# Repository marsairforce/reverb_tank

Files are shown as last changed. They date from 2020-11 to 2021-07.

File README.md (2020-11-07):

# A stand alone spring reverb tank

Here I wanted to investigate using op-amps to drive the tank, rather than to build a tube circuit.

I already built a tube circuit into my Traynor amp, and I am very happy with how good it sounds.

I just had this spare reverb tank sitting on my shelf with nothing to make use of it. If i can build it into a "pedal" type of effect, I can power it from standard guitar pedal power supply and use it in my audio hobby work. Like as an effect for microphone for vocals. Or drums in reaper. Any time reverb is needed so I don't need to use an effect or impulse response, Since these always sound terrible to me.

But then I had the idea, Why not just build both as a stand-alone unit. Have a switch to change between which driver is used.

## Packaging

The reverb tank is quite long. If I could build a 1U rack case for this that might be fun. But then might as well build a power supply so this plugs in. I can create a stripped down version of the op-amp power supply, having a single fixed +/-15V regulated output. That power supply is super awesome. Smooth DC ouput

The challenge is I need to be able to create a metal chassis. or shell out to buy one.

I found one from Bud Industries for about half what the Hammond mfg one was. But the Hammond one is painted. This 1U chasis needs painting then. It is about $100 to get the chassis and lid.

But the idea is I think I can fit this into a 1U chassis.

## Op-Amp Driver

I am really inspired by the design from [Elliot Sound](https://sound-au.com/project34.htm) site.

I find it curious, that when doing a google search I found several foreign websites that look like a pintrest kind of site but caching super old versions of this page, the wording is mostly the same, but the schematic showed a simple LM386 in place there for the driver to the reverb tank.

This makes me question, why?  Because before doing research into this I was thinking about using a 386 audio amplifier IC here. My theory is that it was not able to produce a good quality drive to the reverb tank. Or that the output was somewhat noisy.  Or was it just some amp design used the 386 and threatened to sue him for copyright?

Spend an evening capturing the schematic. And the power supply (see below)

## Tube Driver

I find myself again back on [The Valve Wizard](http://www.valvewizard.co.uk/reverbdriver.html) site. The discussion there is about how the using the EL84 as a driving tube is overkill and waste. Sure. But it does work.And I simply love the sound of it.

So I think I will basically take the same schematic I ended up using in the Traynor amplifier and making it a stand-alone driver into this chassis.

This is loosely based on the [Tube Town Reverb Kit](https://www.tube-town.net/cms/userfiles/media/low-reverb/kit-tubereverb.pdf)

I guess this project I am basically building that thing.

## Power Supply

The first challenge for either approach is I yet again need to build another power supply. Sometimes it feels like all I do is build a power supply for a project and by the time I figure that out I either get bored with the project and have moved on or run out of budget and give up.

If I do tubes, I need the 350V DC and the 6.3V filament supply.

If I do op-amps I need +/-15V. probably the current from the op-amp power supply project. So I can just reuse the same transformer, capacitors and a different regulator. I have a feeling this is going to be more practical. In that it is going to cost less to build, will operate with less need for cooling (e.g. in an audio rack) and have a better chance of fitting into a 1U rack chassis.

So I think I'll just build the op-amp based driver.

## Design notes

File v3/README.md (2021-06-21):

# A second attempt at using op-amps to drive a spring reverb tank

Following the failure of the first attempt and several months, I came back to attempting this again.

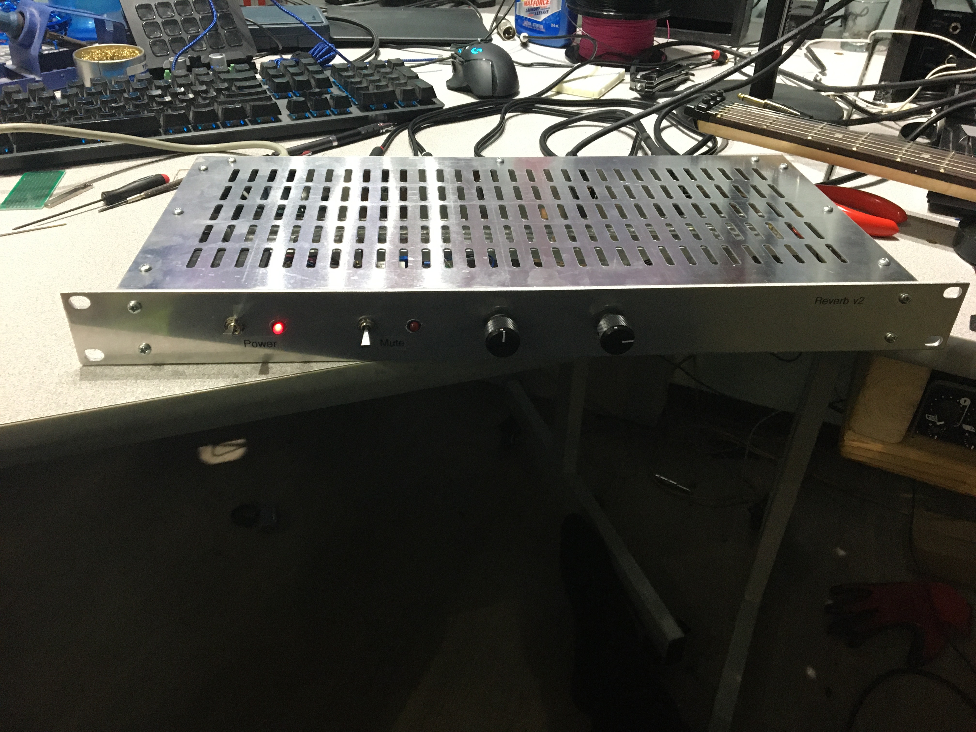
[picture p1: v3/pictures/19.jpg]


This time using some of the knowledge I have learned along the way.

* To use a pre-built power supply module. These Recom power converters are basically cheaper than anything I can build, more efficient, better quality power output, And a single package can not be more convenient.

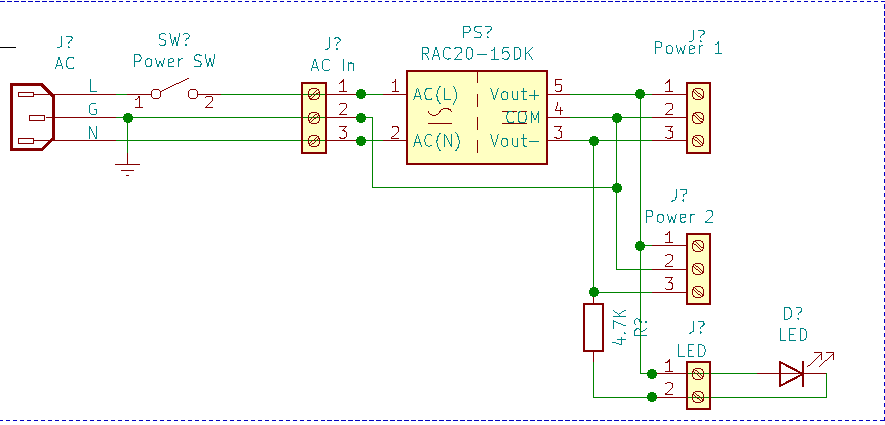
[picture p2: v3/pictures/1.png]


* To use the simple op-amp that powers a push pull output transistor like I had before for my desktop audio amp and speakers. I mean, here I am driving a spring. it doesn't need to be really good quality hifi audio. It just needs to make the spring move enought that we can pick up its sound.

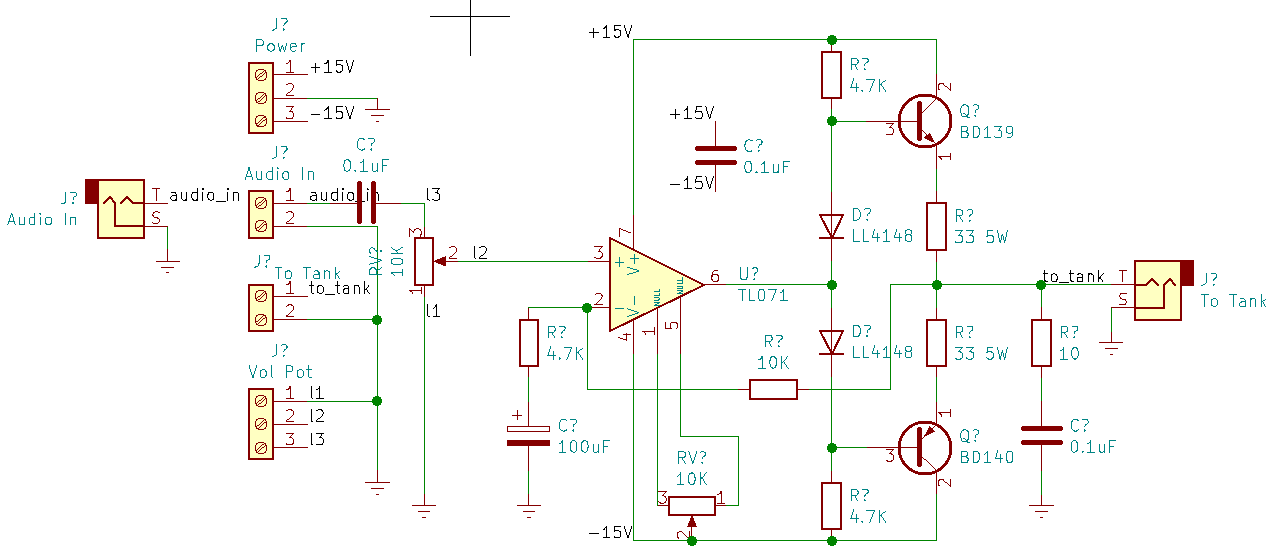
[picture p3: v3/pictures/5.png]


* To use the boost converter I designed for my guitars. Here this is a v2 design I did a while ago but never got around to actually building, because I didn't need it.

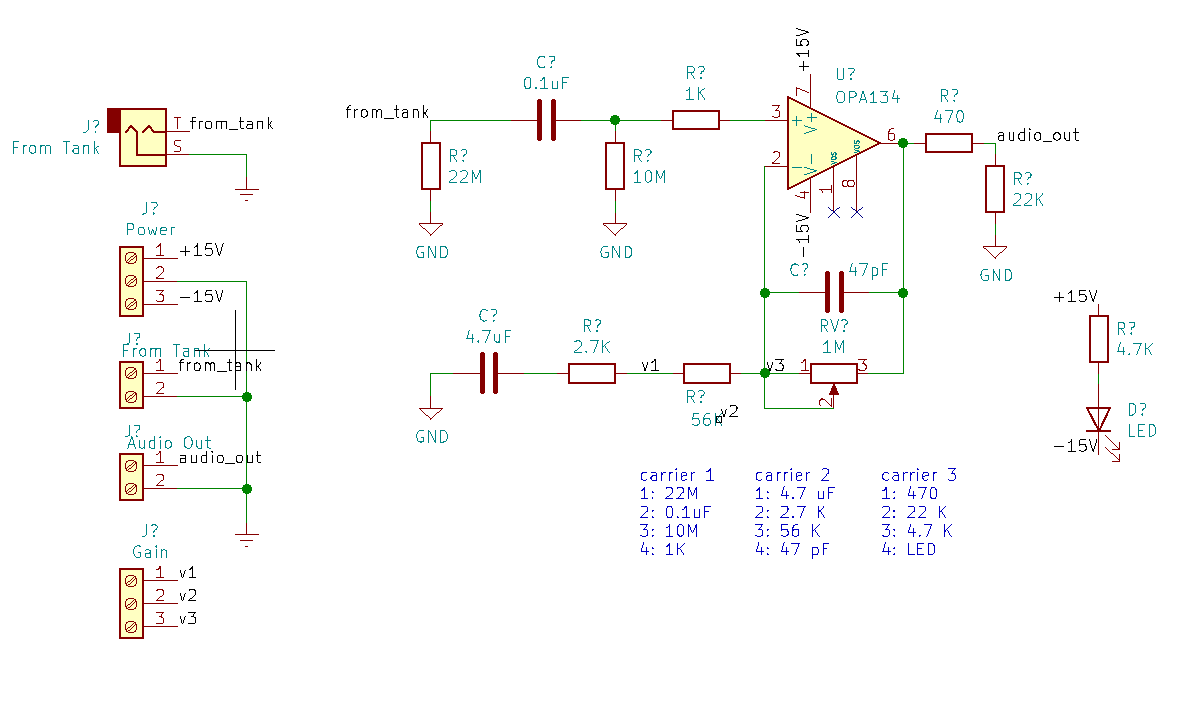
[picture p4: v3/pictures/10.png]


So I set out the Father's day weekend to build 3 small modules.

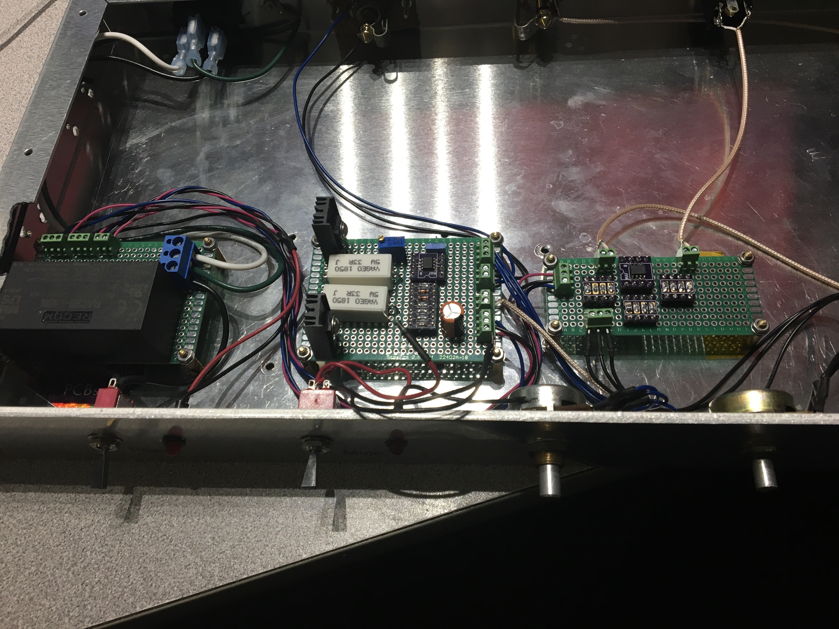
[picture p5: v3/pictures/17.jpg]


They fit into the chassis I had used before. So that is good to recycle it.

This time, testing each component as I go on its own.

First I connected the tank on its own. Using my desk audio amplifier to drive it and just sending it back to my mic preamp to hear how it sounds.  The tank on its own is pretty quiet. Good.

I now have a regular speaker, because i built a speaker box. So connecting the reverb tank driver into a speaker to hear how it works. So the driver now works and is not buzzing. Good.  

And the same for the recovery circuit, to connect it to an audio interface and hear what the output of the tank sounds like. And it is not buzzing. Good.

I was even able to mount the spring element back into the chassis, as I originally wanted to do.

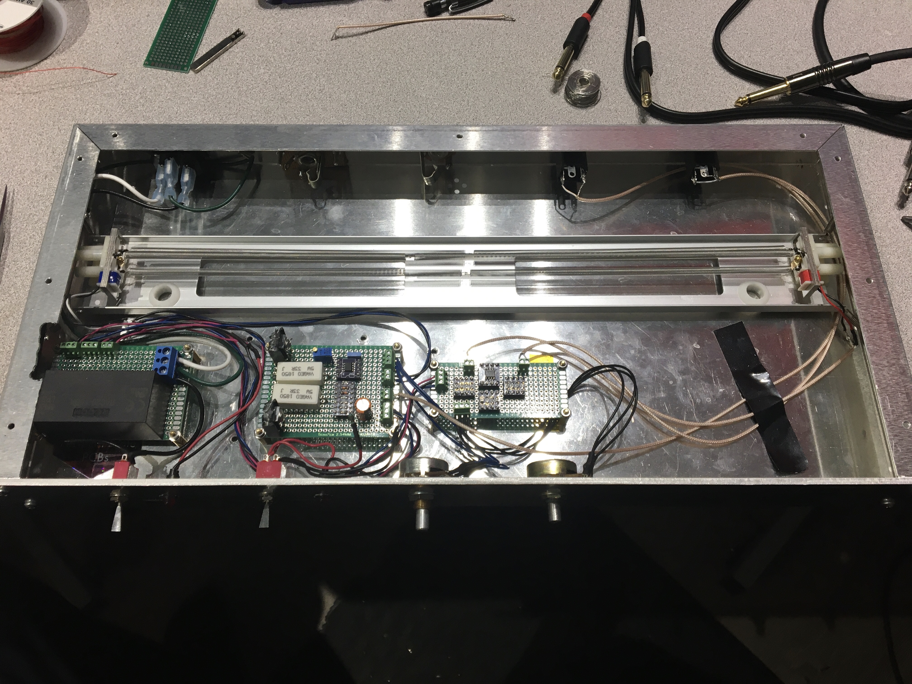
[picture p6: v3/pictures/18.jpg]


## BOM

It works out to around $250

| Part | Link |Cost |
|:--|:--|:--|
| Spring tank | 9AB2C1B | $54 |
| M2.5 standoffs, nuts, washers || $10 |
| 8" 1U rackmount chassis | [Bud Industries](https://www.digikey.ca/product-detail/en/bud-industries/CH-14401/377-1206-ND/428956) | $73 |
| Cover for chassis | [Bud Industries ](https://www.digikey.ca/product-detail/en/bud-industries/C-14431/377-1418-ND/439143) | $31 |
| Potentiometers | [Bourns](https://www.digikey.ca/product-detail/en/bourns-inc/PDA241-SRT02-103A2/PDA241-SRT02-103A2-ND/3781556) | $10 |
| Knobs | [Knurled](https://www.digikey.ca/product-detail/en/kilo-international/OEDL-75-2-5/226-1102-ND/710712) | $22 |
| Jacks | [Mono 6.35mm](https://www.digikey.ca/product-detail/en/switchcraft-inc/L112AX/SC2816-ND/1288931) | $12 |
| Switch | [Toggle](https://www.digikey.ca/product-detail/en/nkk-switches/M2011ES1W01/360-3239-ND/1049310) | $6 |
| Screw terminals | [wire to board](https://www.digikey.ca/product-detail/en/on-shore-technology-inc/OSTVN02A150/ED10561-ND/1588862) | $8 |
| Power Supply | [Recom](https://www.digikey.ca/product-detail/en/recom-power/RAC20-15DK-277/945-RAC20-15DK-277-ND/13890589) | $20 |
| Power connector | [IEC](https://www.digikey.ca/product-detail/en/qualtek/703W-00-02/Q210-ND/245551) | $2 |

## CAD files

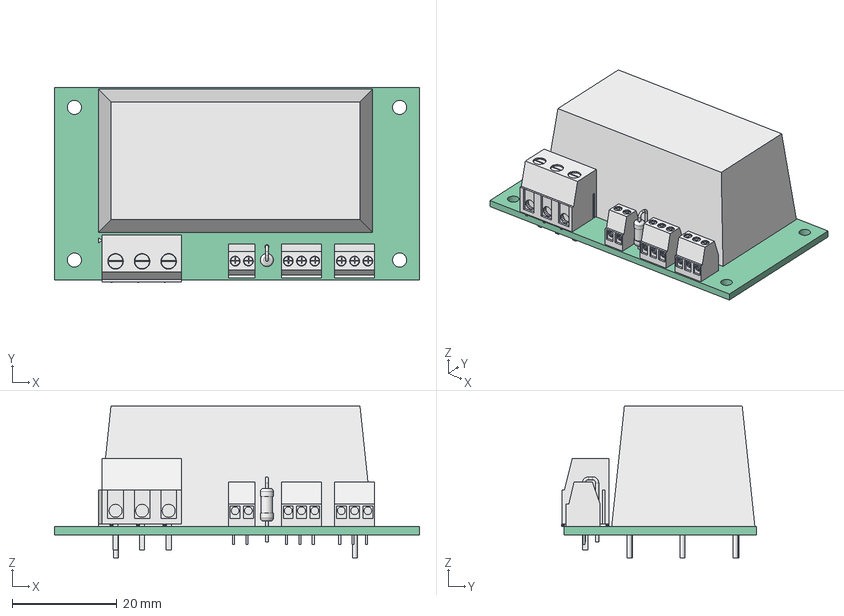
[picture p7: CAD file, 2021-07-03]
v3/power supply.FCStd
69.8 x 37.3 x 29.0 mm
Pcb_7c43
PS1_Fusion_60E0183C
R1_R_Axial_DIN0207_L63mm_D25mm_P254mm_Vertical_60E01AFD
J4_TerminalBlock_1x02_P2_54mm_Horizontal_60DF7D87[2]
J3_TerminalBlock_1x03_P2_54mm_Horizontal_60DF7D67 x 2
J1_OSTTA03416_60DF7D1F

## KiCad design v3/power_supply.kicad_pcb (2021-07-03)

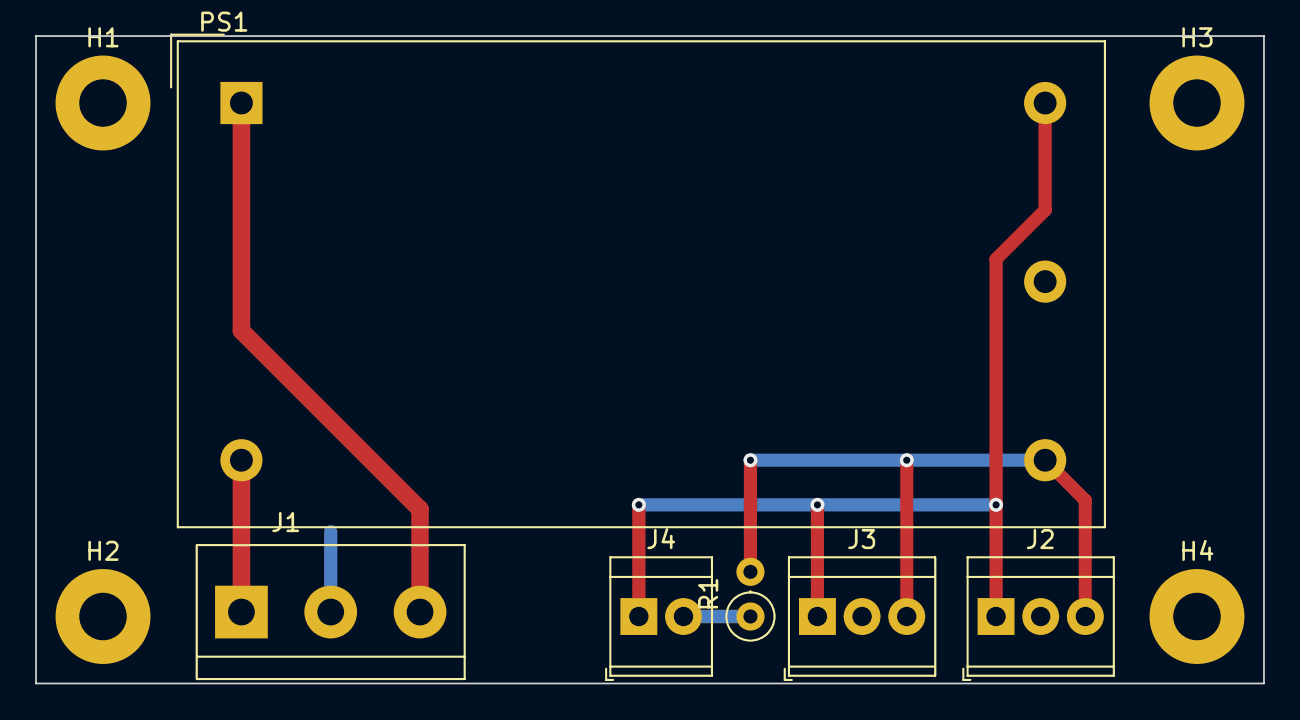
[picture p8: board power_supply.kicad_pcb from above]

Board: 2 copper layers, 69.8 x 36.8 mm, 10 parts (0 on the bottom side), 6 nets.

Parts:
H1, H2, H3, H4: M3; MountingHole_2.7mm_Pad
J1: AC In; TerminalBlock-3_P5.08mm
J2: Power 1; TerminalBlock_1x03_P2.54mm_Horizontal
J3: Power 2; TerminalBlock_1x03_P2.54mm_Horizontal
J4: LED; TerminalBlock_1x02_P2.54mm_Horizontal
PS1: RAC20-15DK; Converter_ACDC_Recom_RAC20-xxDK_THT
R1: 4.7K; R_Axial_DIN0207_L6.3mm_D2.5mm_P2.54mm_Vertical

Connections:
/L: J1.1, PS1.2
/N: J1.3, PS1.1
GND: H1.1, H2.1, H3.1, H4.1, J1.2, J2.2, J3.2, PS1.4
unnamed: J2.1, J3.1, J4.1, PS1.5
unnamed: J2.3, J3.3, PS1.3, R1.2
unnamed: J4.2, R1.1

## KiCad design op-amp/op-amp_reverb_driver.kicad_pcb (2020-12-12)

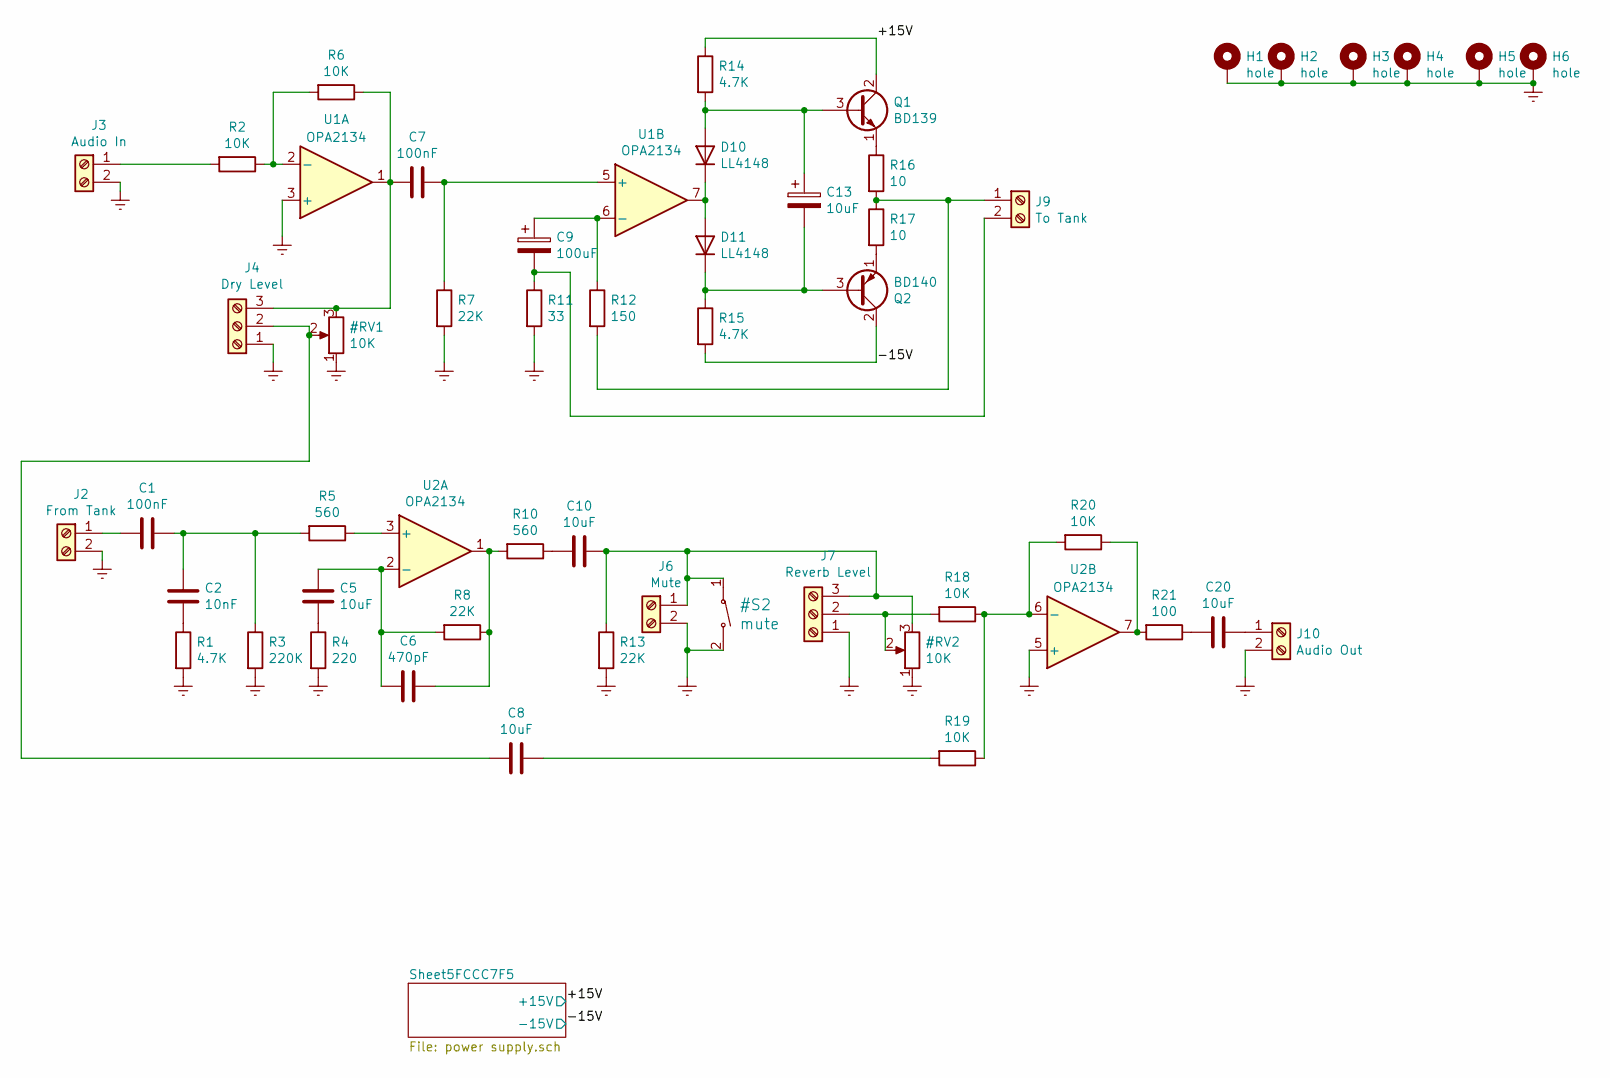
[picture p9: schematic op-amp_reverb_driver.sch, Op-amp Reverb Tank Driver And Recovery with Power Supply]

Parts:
C1, C7: 100nF; C_0603_1608Metric; Voltage 35V
C2: 10nF; C_0603_1608Metric
C5, C8, C10, C20: 10uF; C_0805_2012Metric
C6: 470pF; C_0603_1608Metric
C9: 100uF; CP_Elec_8x10.5; Voltage 50V
C13: 10uF; CP_Elec_4x5.8; Voltage 50V
D10, D11: LL4148; D_MiniMELF
H1, H2, H3, H4, H5, H6: hole; Mounting_Hole_Plated_M2.5
J2: From Tank; TerminalBlock_1x02_P2.54mm_Horizontal
J3: Audio In; TerminalBlock_1x02_P2.54mm_Horizontal
J4: Dry Level; TerminalBlock_1x03_P2.54mm_Horizontal
J6: Mute; TerminalBlock_1x02_P2.54mm_Horizontal
J7: Reverb Level; TerminalBlock_1x03_P2.54mm_Horizontal
J9: To Tank; TerminalBlock_1x02_P2.54mm_Horizontal
J10: Audio Out; TerminalBlock_1x02_P2.54mm_Horizontal
Q1: BD139; TO-126-3_Vertical
Q2: BD140; TO-126-3_Vertical
R1, R14, R15: 4.7K; R_0603_1608Metric
R2, R6, R18, R19, R20: 10K; R_0603_1608Metric
R3: 220K; R_0603_1608Metric
R4: 220; R_0603_1608Metric
R5, R10: 560; R_0603_1608Metric
R7, R8, R13: 22K; R_0603_1608Metric
R11: 33; R_1210_3225Metric
R12: 150; R_0603_1608Metric
R16, R17: 10; R_1210_3225Metric
R21: 100; R_0603_1608Metric
U1, U2: OPA2134; SOIC-8_3.9x4.9mm_P1.27mm

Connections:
/+15V: Q1.2 (C), R14.1; also elsewhere on the board
/-15V: Q2.2 (C), R15.2; also elsewhere on the board
unnamed: C1.1, C2.1, R3.1, R5.2
unnamed: C1.2, J2.1
unnamed: C2.2, R1.1
unnamed: C5.1, C6.1, R8.2, U2.2 (-)
unnamed: C5.2, R4.1
unnamed: C6.2, R8.1, R10.2, U2.1
unnamed: C7.1, R7.1, U1.5 (+)
unnamed: C8.1, R19.2
unnamed: C9.1, R12.1, U1.6 (-)
unnamed: C9.2, J9.2, R11.1
unnamed: C10.2, R10.1
unnamed: C13.1, D10.2 (A), Q1.3 (B), R14.2
unnamed: C13.2, D11.1 (K), Q2.3 (B), R15.1
unnamed: C20.1, J10.1
unnamed: C20.2, R21.1
unnamed: D10.1 (K), D11.2 (A), U1.7
unnamed: J3.1, R2.2
unnamed: J9.1, R12.2, R16.2, R17.1
unnamed: Q1.1 (E), R16.1
unnamed: Q2.1 (E), R17.2
unnamed: R2.1, R6.2, U1.2 (-)
unnamed: R5.1, U2.3 (+)
unnamed: R18.1, R19.1, R20.2, U2.6 (-)
unnamed: R20.1, R21.2, U2.7

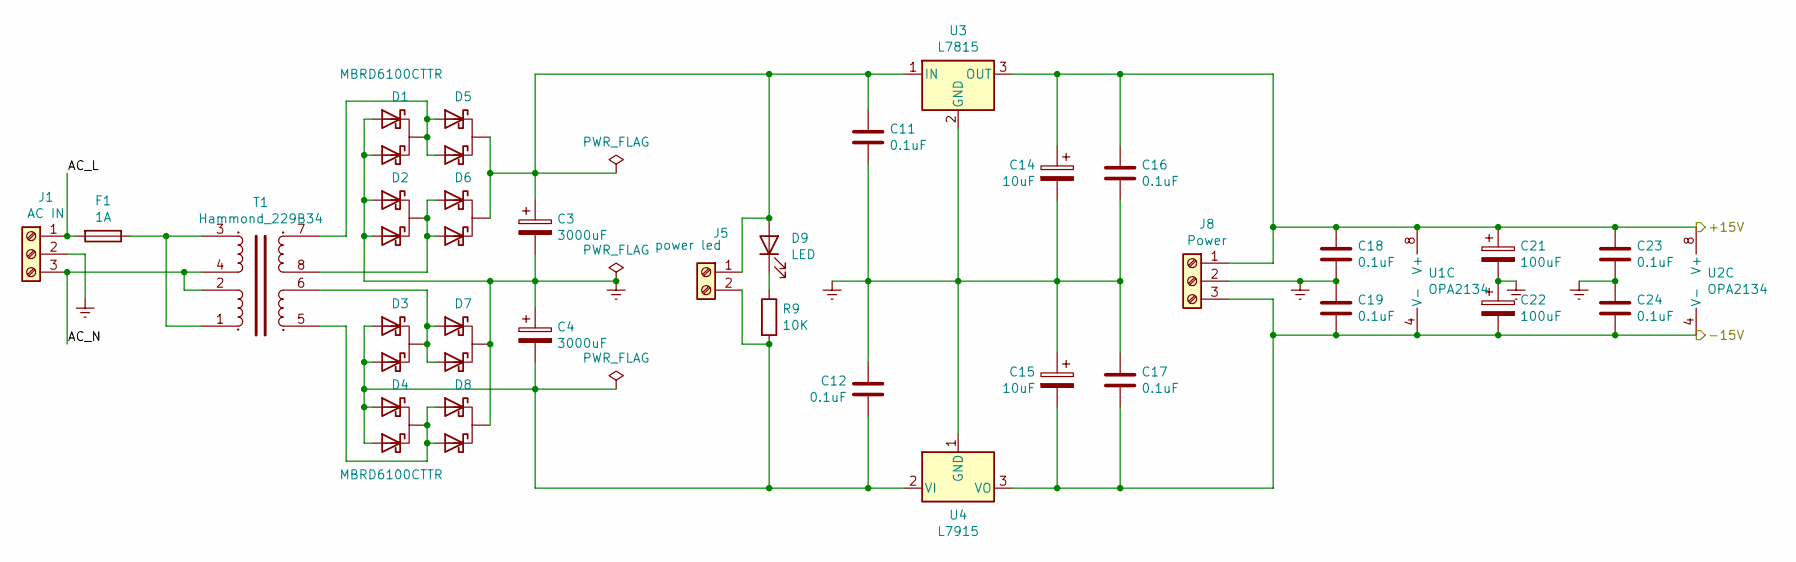
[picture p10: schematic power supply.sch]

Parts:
C3, C4: 3000uF; CP_Elec_18x22; Voltage 35V; Digi-Key_PN ‎P122503CT-ND‎
C11, C12, C16, C17: 0.1uF; C_0603_1608Metric; Voltage 25V; Digi-Key_PN 490-14359-2-ND
C14, C15: 10uF; C_0805_2012Metric; Voltage 50V; Digi-Key_PN ‎PCE5154CT-ND‎
C18, C19, C23, C24: 0.1uF; C_0603_1608Metric; Voltage 35V
C21, C22: 100uF; CP_Elec_8x10.5; Voltage 50V
D1, D2, D3, D4, D5, D6, D7, D8: MBRD6100CTTR; TO-252-2; Digi-Key_PN 1655-1487-1-ND
D9: LED; D_0603_1608Metric; Digi-Key_PN 160-1182-1-ND
F1: 1A; Fuseholder5x20_horiz_open_lateral_Type-II; Digi-Key_PN F4714-ND
J1: AC IN; TerminalBlock-3_P5.08mm; Digi-Key_PN ED2581-ND
J5: power led; TerminalBlock_1x02_P2.54mm_Horizontal; Digi-Key_PN ED10561-ND‎
J8: Power; TerminalBlock_1x03_P2.54mm_Horizontal
R9: 10K; R_0603_1608Metric; Digi-Key_PN CRCW06031K50FKEAC
T1: Hammond_229B34; Transformer_Hammond_229B34; Digi-Key_PN 229B34
U1, U2: OPA2134; SOIC-8_3.9x4.9mm_P1.27mm
U3: L7815; TO-252-2
U4: L7915; TO-252-2

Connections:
/+15V: C14.1, C16.1, C18.1, C21.1, C23.1, J8.1, U1.8 (V+), U2.8 (V+), U3.3 (OUT); also elsewhere on the board
/-15V: C15.2, C17.2, C19.2, C22.2, C24.2, J8.3, U1.4 (V-), U2.4 (V-), U4.3 (VO); also elsewhere on the board
/Sheet5FCCC7F5/AC_L: F1.2, J1.1
/Sheet5FCCC7F5/AC_N: J1.3, T1.2, T1.4
unnamed: C3.1, C11.1, D5.2 (A), D6.2 (A), D9.2 (A), J5.1, U3.1 (IN)
unnamed: C4.2, C12.2, D3.1 (K), D3.3 (K), D4.1 (K), D4.3 (K), J5.2, R9.2, U4.2 (VI)
unnamed: D1.2 (A), D5.1 (K), D5.3 (K), T1.7
unnamed: D2.2 (A), D6.1 (K), D6.3 (K), T1.8
unnamed: D3.2 (A), D7.1 (K), D7.3 (K), T1.6
unnamed: D4.2 (A), D8.1 (K), D8.3 (K), T1.5
unnamed: D9.1 (K), R9.1
unnamed: F1.1, T1.1, T1.3

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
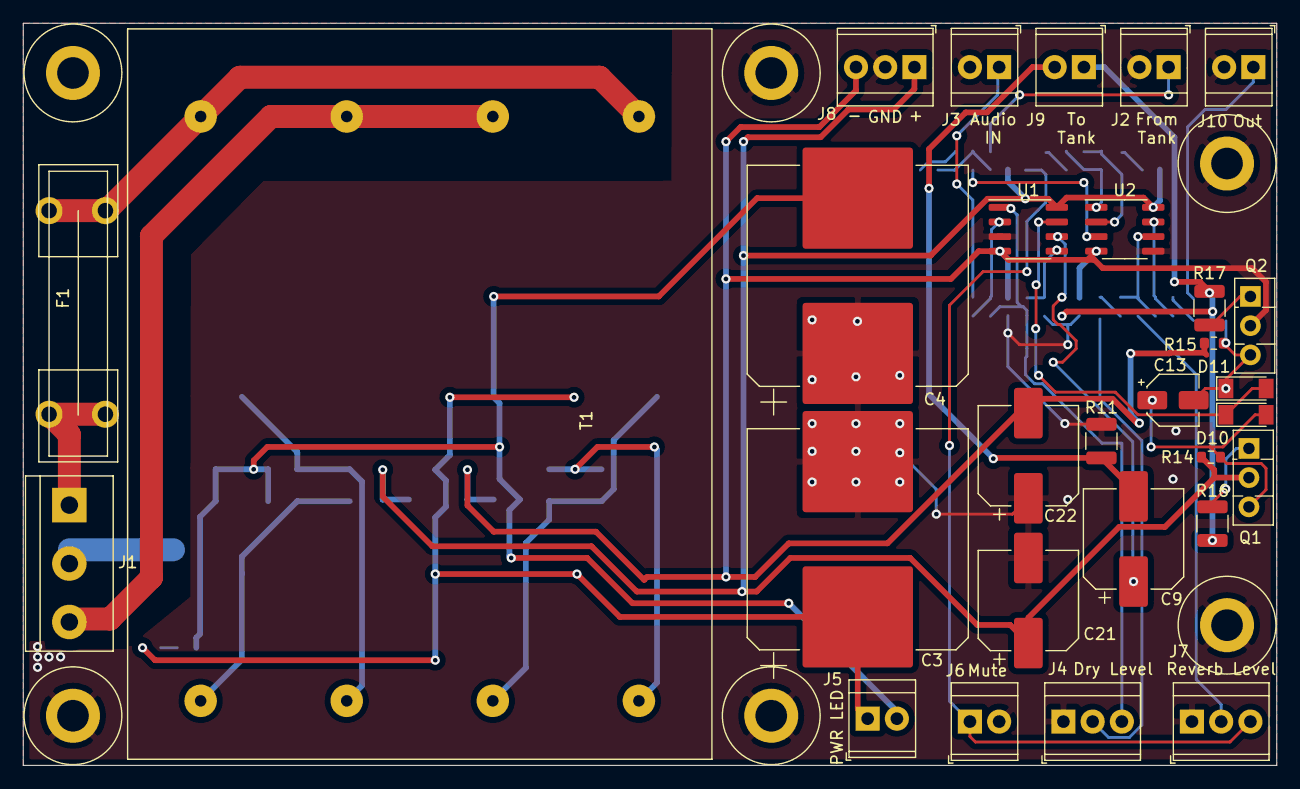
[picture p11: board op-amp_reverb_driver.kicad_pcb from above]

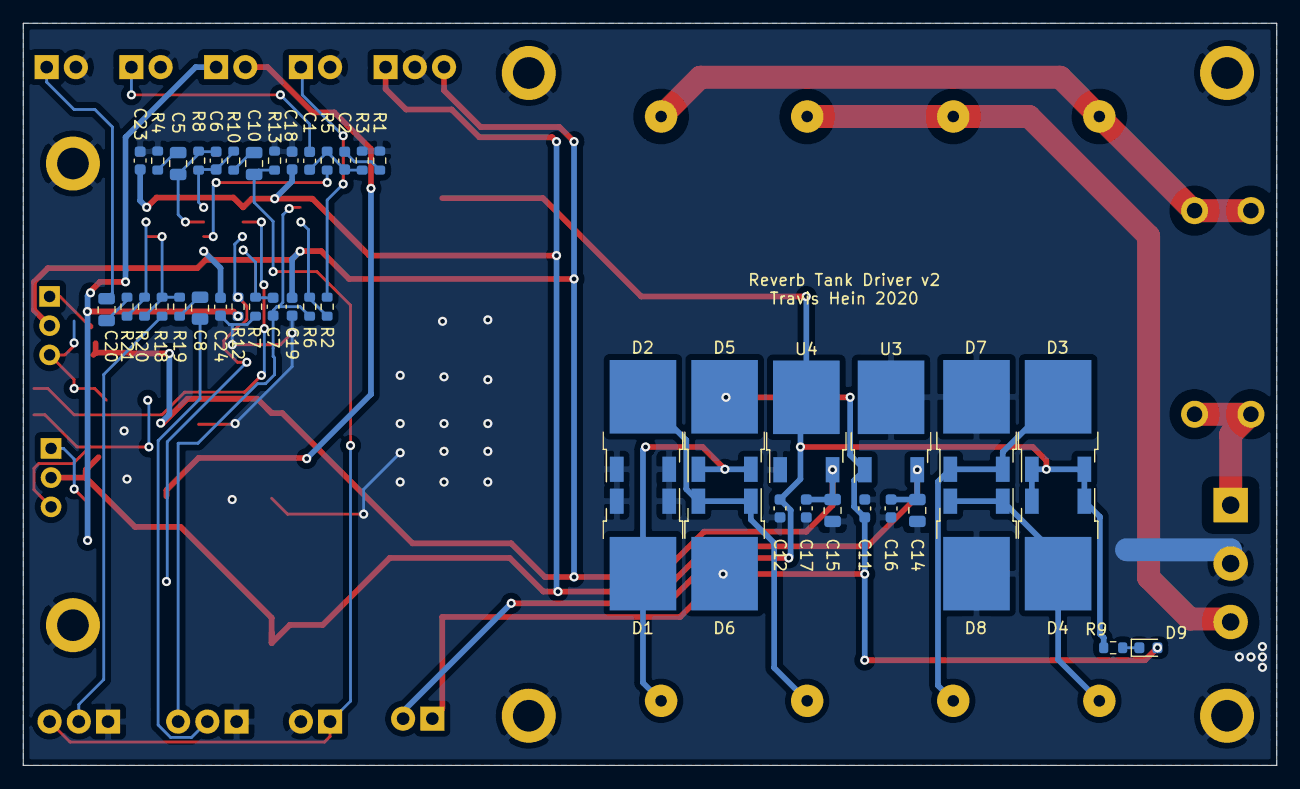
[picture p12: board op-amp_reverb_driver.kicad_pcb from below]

Board: 2 copper layers, 109.0 x 64.5 mm, 80 parts (45 on the bottom side), 41 nets.

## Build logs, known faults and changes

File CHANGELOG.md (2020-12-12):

# Changes

## 2020-12-12

Read [up](https://e2e.ti.com/support/amplifiers/f/14/t/619552?OPA2134-OPA2134-running-hot) on why opa2134 run hot.
They are very different than TL072.

Try removing C9 and C5, replace with short. The capacitor here in series with feedback to ground makes no sense to me.But it doesn;t help the overheating. put them back.

Maybe I should just try TL072 in this shit circuit then.
Order some from aliexpress.

Now have to park this until the parts come in. Fucking shit.

Mount the transitors on the holse on the PCB. I tried removing 2 screws on the end in case I was flexing the PCB and that was causing connections to SMD parts to work intermittantly. But now having the holes free to bolt down the transistors is handy.  This is a large pile of fail.

## 2020-12-11

Angrily thinking about how to shield the reverb tank transducer from noise. Like if i had sheet metal i could solder into a box to go around the transducer. steel from a coffee can? Maybe steel tape? I have no good idea what to do here.

Had the idea to try to hook the output of the tank directly to audio interface. When I use balanced input to the coil, it sounds clean. when i connect ground to the cable. it sounds bad. this might be an audio interface connection thing.. But it is silent this way.

Then tested. with output coil connected to audio interface, turn on the power to the chassis. And there is that buzz. So the noise we here is this coil picking up the noise from this transformer. I would need much better shielding to protect the sensitive coil from the transformer. I don't have this. for now.

But this motivated me to try running the tank outside of the chassis.

Mount the spring back into the tank. And run cables to it. It seems to work ok without the buzz.

Test playing on it. It worked well. But then it got suddenly louder when i bumped it, then quieter. so something is loose someplace. Remove the board and resolder a bunch of parts. and the op-amps. put it back. it seems more stable now.

So I am going to mount jacks on the chassis and run the tank externally. I guess this will be good to keep the vibrations from the desk from dangling the springs. But I think also the steel in the reverb tank chassis is doing a much better job of shielding the coil. And I would likley need something like this around the power transformer and/or the spring rails inside the 1U chassis. But I don't really have the space or the hardware to experiment wit this. And really since it does work this way with the tank out of the chassis. fuck it, i am just going to run the tank out of the chassis for now. I need to find a TRS 1/4 jack so I can use a stereo connector to send to the tank, because the send is not grounded. wtf right. What if i just ground this fuck. No., that gets loud and buzzy. this must be what happened when i bumped the case, the ring wire on the temp jack i am using touched the chassis. grounding the ring.

But i still randomly smell burning thing. and the op-amps seem to get pretty hot still. How come? I wonder if it is the board itself. There are the +/-15V traces there.

Sure the buzz is gone when i have connected external tank with the proper connectors. But I should figure out what is making that hot smell before i put this thing back together.

Spent an hour trying to find the 9 screws. what the hell. Where did i even put them.

## 2020-12-10

Ideas to try to fix the reverb tank:

check wires. This sounds like a ground loop or disconnected input kind of problem, not an AC hum kind of problem. - pulling the wires for the from tank, makes the buzz go away.
measure the resistance from the transducer. Maybe moving it around i ripped a wire in the transducer. - it is ok, a few hundred ohms.
try adding a 1M resistor on the output jack. Maybe it is just not very well connected to audio cable with just the output capacitor. - no change.
try shielding the output jack. Maybe the open frame jack picks up room noise. it is not the jack, but having the reverb return connected causes the buzz.
Try removing the board from the chassis, proximity to metal. - no change
Perhaps mounting the board flexed it a bit and some solder joint(s) got loose and there is a break in the signal path. - things look ok. but i guess a more detailed check might find something.
I really think the reverb return transducer is picking up noise. I should try to shield this. - Nope

Check the output wire. The ground connection to the output jack was a bit loose. But this does nothing to help the buzz, because the metal sleeve on the jack is already grounded to the case.

I am able to make it kind of work if i put the reafir software noise filter after it. But this is an epic fail. The buzz makes this unusable.

Try to connect the transducer directly to the audio interface. I still hear a fucking buzz. So its likely this transducer is damaged, or the impedance is incorrect for use with line audio. How come I didn't have any of these problems with the tube driver in the amp? Just sayin..

## 2020-12-09

Digikey parts finally arrived.

Assemble the reverb tank. This front panel detail that I hate.

Test it. It sounds ok. Put it together. Build patch cables. Rack it.

Fucking buzz sound. What! This was not there before. I would have noticed this much buzz. Why is there buzz now.

Take it apart. Try to replace the chinese opa2134 op amps with the ones I now have from digikey. Nope, still buzz. Try to disconnect the mute switch. maybe that is picking up noise from the transformer. Nope.

I know this was not buzzing before. I ran it for an entire evening. The only other thing I can think of is the board is now mounted closer to the chassis. Maybe it is picking up some AC noise by the proximity to the chassis and there is some kind of coupling going on. I would need to take this apart and pull the board out to confirm this. But right now I am so dissappointed at this epic many month long failure of a project. This buzzing makes it not even usable. This buzz was not here before.

## 2020-12-04

Drill holes for IEC power connector, 1/4 jacks on the back.

Mount the spring assembly into the chassis.

Drill holes to mount the circuit board.

Pick up some longer M2.5 bolts. I need the spacers to come in before I can properly mount this.

Wire up the board.

* transducers on spring assembly.
* jacks on back of chassis.
* power connector to board AC input.
* potentiometers on wires.

Connect the power supply.

Discover in testing the PNP transistor was backwards on the scehmatic. That was why it was getting pretty hot when driving it over about 9V.

Desolder the transistors and put them on wires. I'll bolt them down to the chassis then. This is already a screw up here becaue the kicad footprint was incorrect. Now it is just more awesome.

But, it does function well.

The test case was to connect the audio out from audio interface channel into it, and then the output of this back to an input on audio interface. I played youtube audio through it. It seems to sound good to me.

I need to get the switches and knobs for front panel and pcb mounting spacers to come in the next DigiKey order.

## 2020-12-03

Finish assembling the board. Need to test it. Leave out the voltage regulators so I can power it with my power supply.

Designing by sketching out the front panel and rear connector layout.

## 2020-12-02

The boards arrived in the mail. Start assembling them.

## 2020-11-07

* Spend all afternoon laying out a board.
* Hand it in to OSHPark to be made. $74.42

Now waiting for the board to get made and mailed to me.

## 2020-11-06

* Kick off the project.
* Capture schematic from [ESD Project 34](https://sound-au.com/project34.htm)
* Borrow power supply design from op-amp power supply project. Make it a single +/-15V fixed regulator. Super simple stuff here.
* Get to the point where I can start laying things out in pcbnew. But losing steam because its 3 AM.

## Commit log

2020-11-07 lay out the PCB and submit it to OSHPark
    [op-amp_reverb_driver.kicad_pcb, op-amp_reverb_driver.sch]
2020-12-12 at a natural point of fail
    [op-amp_reverb_driver.kicad_pcb, op-amp_reverb_driver.sch, power supply.sch]
2021-06-21 revisit the reverb tank. create a v3. This time it works well, even with the springs inside the 1U chassis. I used experience and circuit patterns from my desktop amp, and also built the boost circui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
    [v3.kicad_pcb, v3.sch]
2021-07-03 add pcb and cad model for the power supply module
    [driver.sch, power supply.FCStd, power_supply.kicad_pcb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]
